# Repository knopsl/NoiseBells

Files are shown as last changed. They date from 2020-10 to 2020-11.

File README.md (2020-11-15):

# Noise Bells synthesizer module

This is a percussion and drone synth module based on ideas presented in the 2015 Hackaday article "[Logic noise: More CMOS cowbell!](https://hackaday.com/2015/04/10/logic-noise-more-cmos-cowbell/)" by Elliot Williams. The PCB and front panel are Kosmo format but the same circuit could be implemented in Eurorack format, or other ±12V formats, with no changes other than PCB, panel, and jack dimensions.

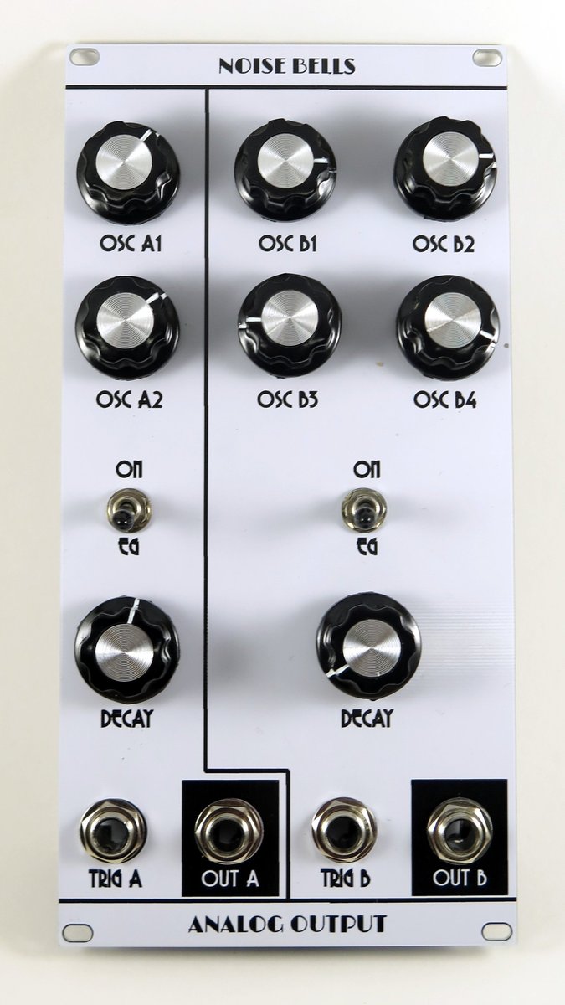
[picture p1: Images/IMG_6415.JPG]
Noise Bells module


The module consists of two separate sections. One is a 2-oscillator circuit based on the "cowbell" section of the Hackaday article. The other is a 4-oscillator circuit, lying sort of halfway between the "cowbell" and "hi hat" designs and designed to use most of the IC functionality left over from the "cowbell" side. Whether it leans more toward bell or cymbal sounds I leave for you to decide. The two sections differ only in the number of oscillators and XORs used.

Aside from a few component value changes, notably a larger capacitor allowing longer decay times, there are a couple of significant modifications to Williams's design:

* The 2-diode "VCA" has been replaced by a 4066 analog switch "VCA" as discussed in the article's comments and at [http://files.electro-music.com/forum/viewtopic.php?highlight=diode+vca&t=23960](http://files.electro-music.com/forum/viewtopic.php?highlight=diode+vca&t=23960). 
* A switch has been added to bypass the EG/VCA section, sending the output of the final XOR straight to the output buffer. This allows using the module for noisy drones.

Pots are used for variable oscillator frequencies and amplitude envelope decay rates. Trigger B input is normalled to Trigger A.

For BOM, schematics, and PCB layout see the [Docs](Docs) folder. The build should be entirely straightforward except, on the first run boards, for the issues mentioned below. Presumably any small signal NPN transistor can be substituted for the 2N3904, though I have not tested any others. 

**Note:** On the first run PCBs the delay pots are connected incorrectly. To fix this, bend the middle leg up and solder it to the leg on its right (pin 2 to pin 3):

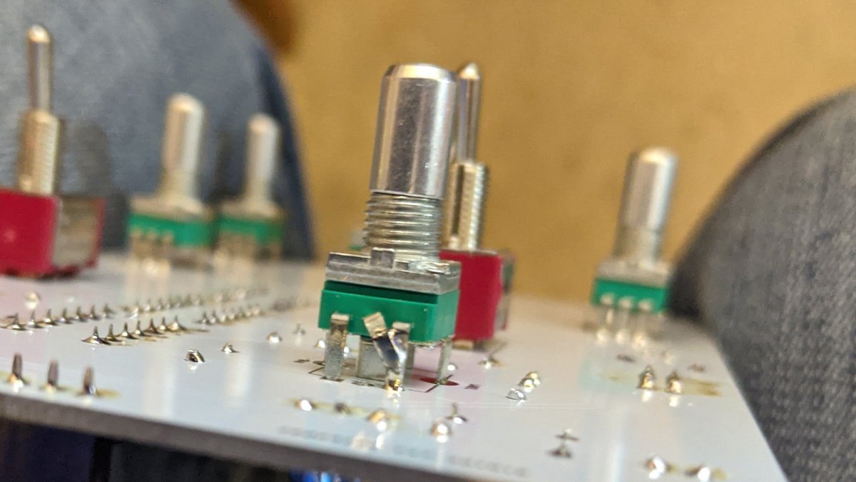
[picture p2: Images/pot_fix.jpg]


This is only for the two delay pots. The six oscillator frequency pots are okay.

Also two capacitors are marked '10uF (47uF?)'. These are 10µF. Unless you like 47µF better of course.

These problems are corrected in the current version.

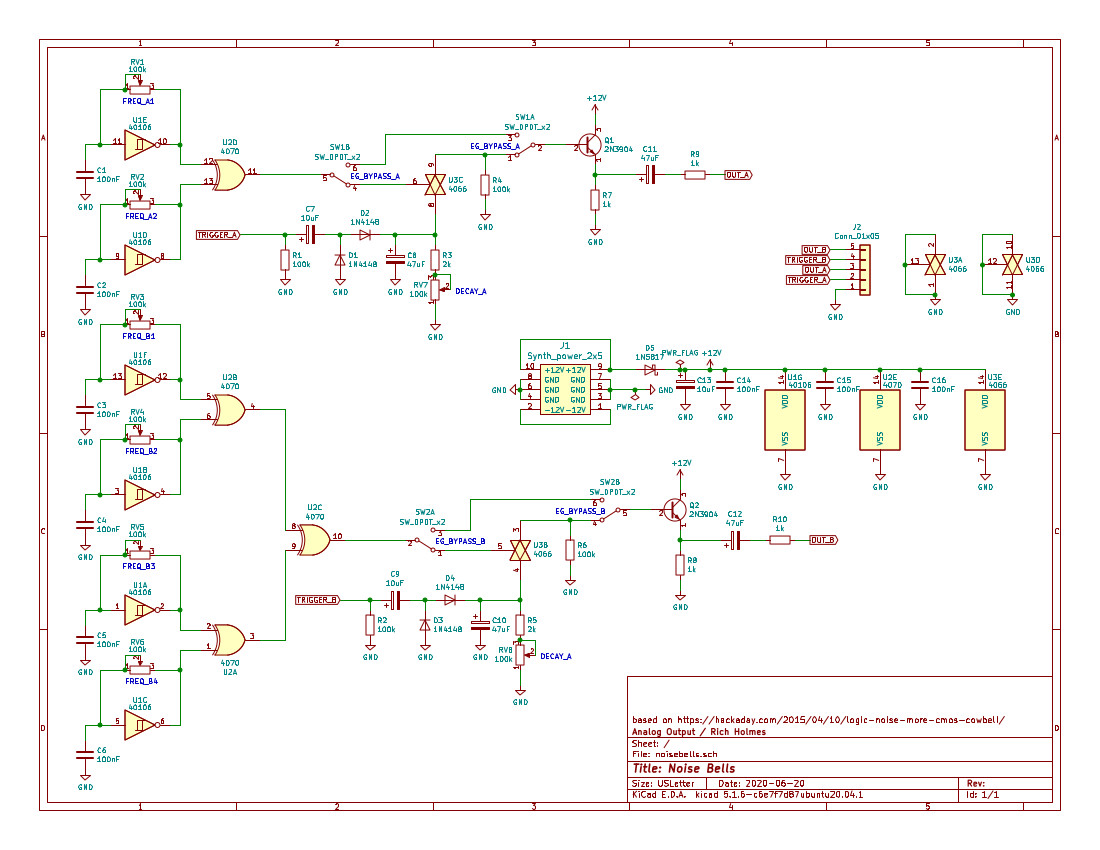
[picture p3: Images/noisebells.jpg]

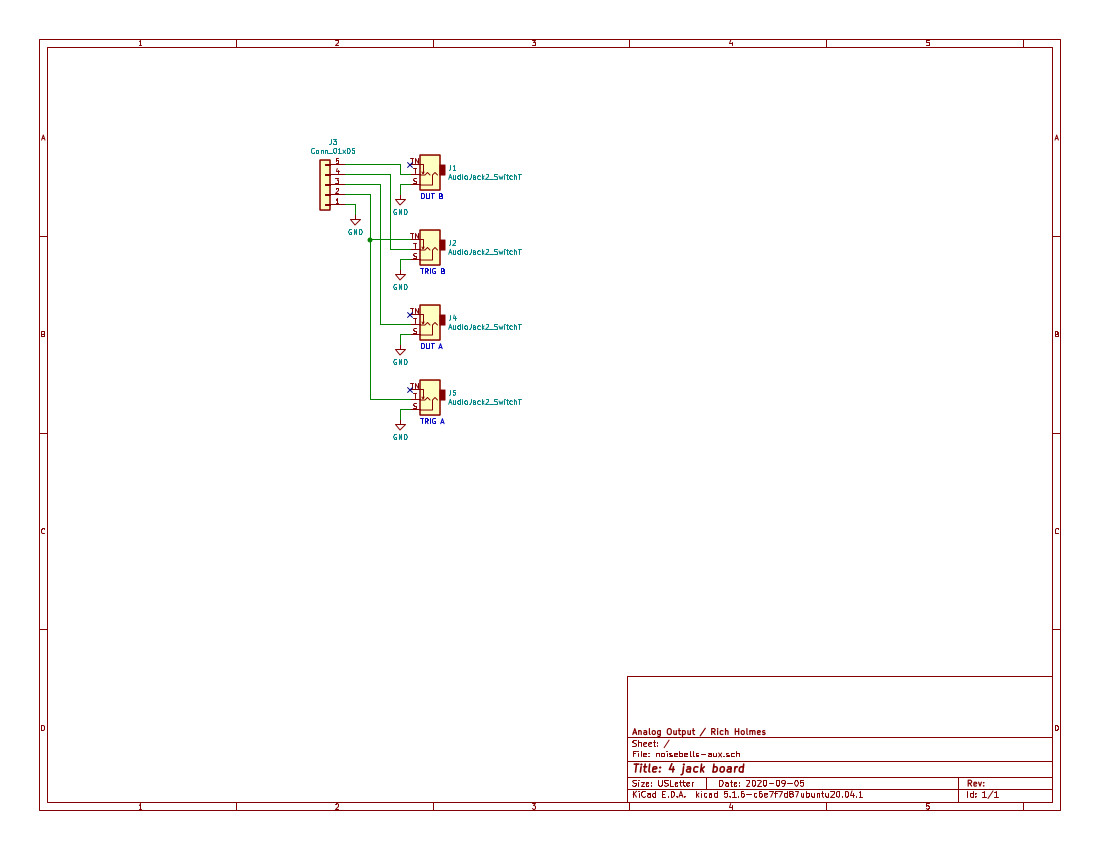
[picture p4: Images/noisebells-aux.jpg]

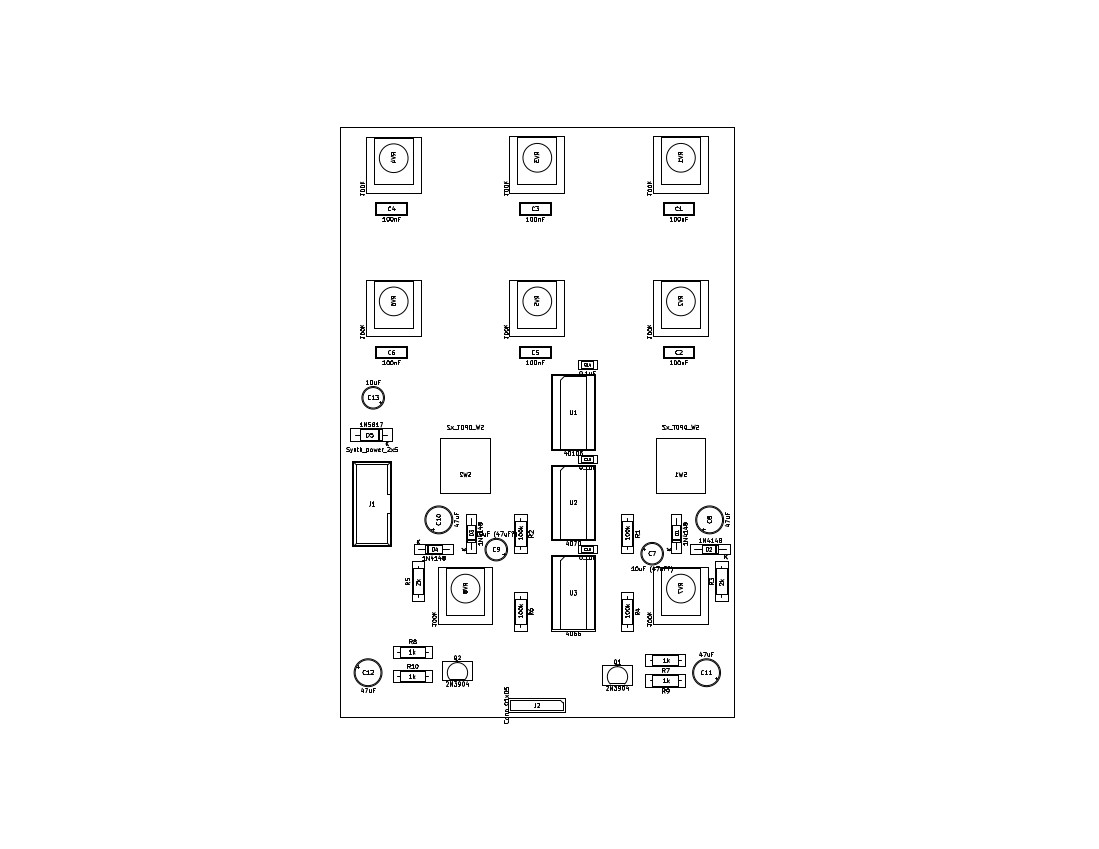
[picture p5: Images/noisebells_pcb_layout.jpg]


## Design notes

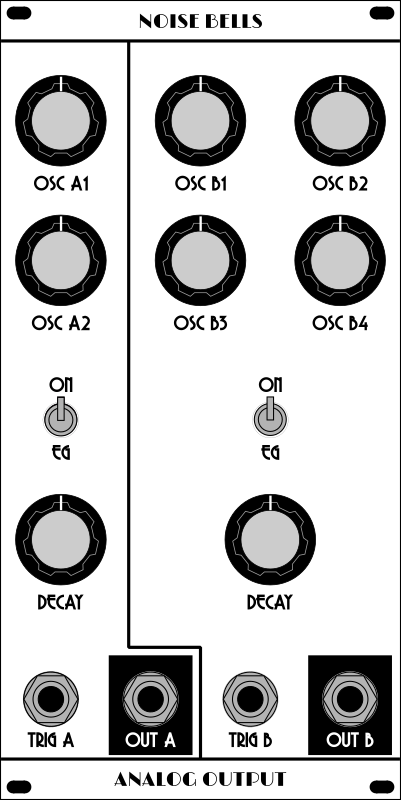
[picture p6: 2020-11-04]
Hardware/Panel/noisebells.png

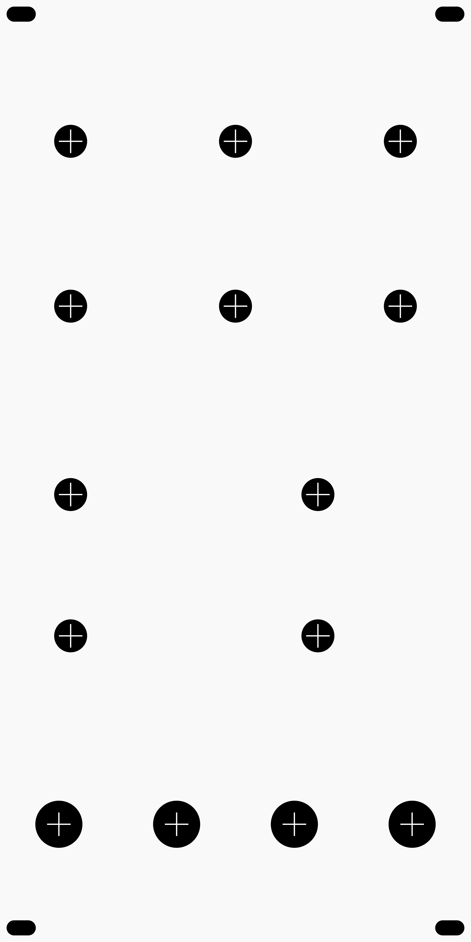
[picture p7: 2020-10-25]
Hardware/Panel/noisebells_holes.png

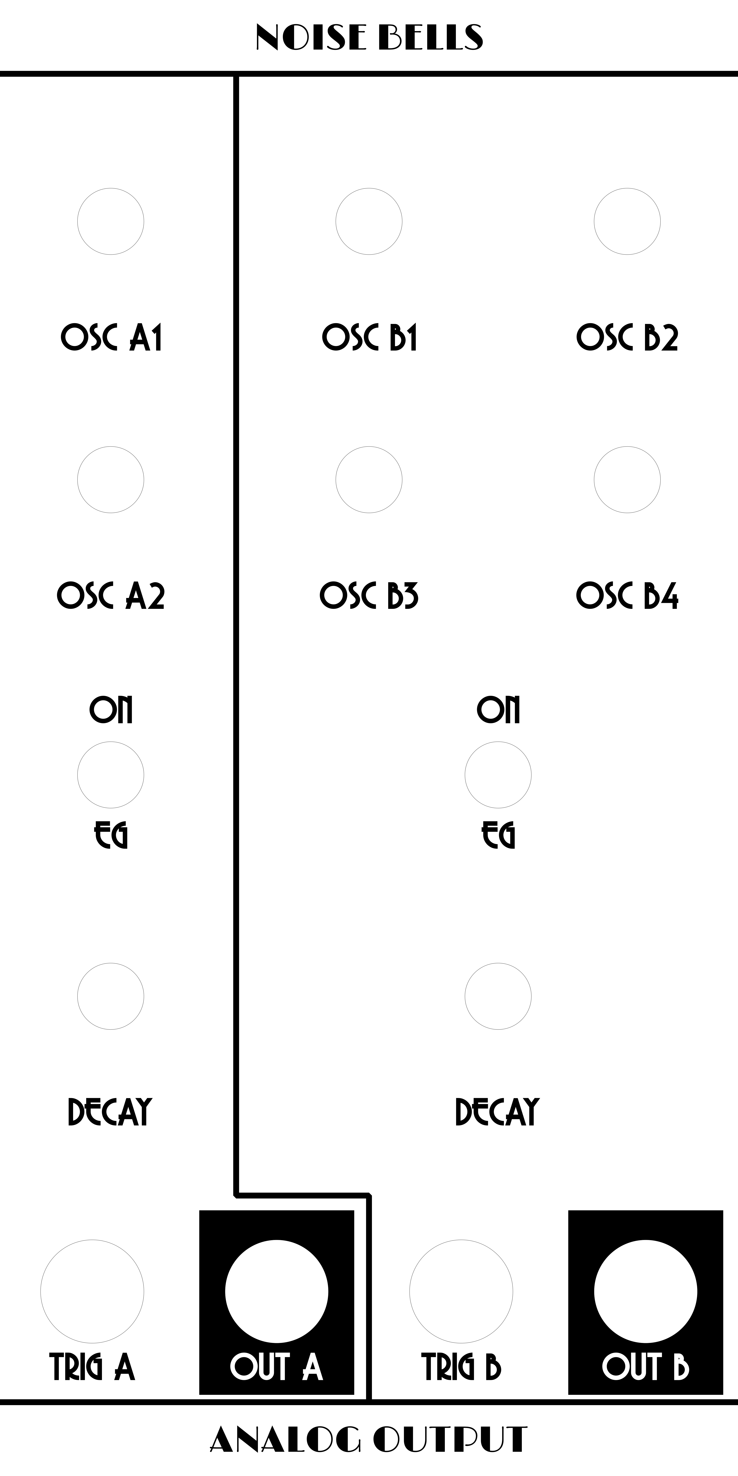
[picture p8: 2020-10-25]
Hardware/Panel/noisebells_art.png

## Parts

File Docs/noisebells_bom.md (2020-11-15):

# Noise Bells BOM

## Main board

| Value | Qty | Part | Description | Vendor |
| ----- | --- | ---- | --- | --- |
| C1, C2, C3, C4, C5, C6 | 6 | 100nF | Polystyrene capacitor | Tayda A-564 |
| C7, C9, C13 | 2 | 10uF | Electrolytic capacitor | Tayda A-4349 |
| C8, C10, C11, C12 | 4 | 47uF | Electrolytic capacitor | Tayda A-4518 |
| C14, C15, C16 | 3 | 0.1uF | Ceramic capacitor | Tayda A-553 |
| D1, D2, D3, D4 | 4 | 1N4148 | 100V 0.15A standard switching diode, DO-35 | Tayda A-157 |
| D5 | 1 | 1N5817 | 20V 1A Schottky Barrier Rectifier Diode, DO-41 | Tayda A-159 |
| J1 | 1 | Synth_power_2x5 | 2x5 pin shrouded header | Tayda A-2939 |
| J2 | 1 | Conn_01x05 | 2.54 mm 5 pin socket | Tayda A-196 (cut to size) |
| Q1, Q2 | 2 | 2N3904 | 0.2A Ic, 40V Vce, Small Signal NPN Transistor, TO-92 | Tayda A-111 |
| R1, R2, R4, R6 | 4 | 100k | Resistor | Tayda A-2248 |
| R3, R5 | 2 | 2k | Resistor | Tayda A-2307 |
| R7, R8, R9, R10 | 4 | 1k | Resistor | Tayda A-2200 |
| RV1, RV2, RV3, RV4, RV5, RV6, RV7, RV8 | 8 | B100k | 9mm vertical board mount potentiometer | Tayda A-1848 |
| SW1, SW2 | 2 | SW_DPDT_x2 | DPDT switch, on-on | Tayda A-3188 |
| U1 | 1 | 40106 | Hex Schmitt trigger inverter | Tayda A-015 |
| U2 | 1 | 4070 | Quad Xor 2 inputs | Tayda A-892 |
| U3 | 1 | 4066 | Quad Analog Switches | Tayda A-555 |
| | 3 | | 14 pin DIP sockets | Tayda A-004 |
| | 8 | | Knobs | |
    
## Jacks board

| Value | Qty | Part | Description | Vendor |
| ----- | --- | ---- | --- | --- |
| J1, J2, J4, J5 | 4 | AudioJack2_SwitchT | Audio Jack, 2 Poles (Mono / TS), Switched T Pole (Normalling) | Tayda A-1121 |
| J3 | 1 | Conn_01x05 | 2.54 mm 5 pin header | Tayda A-197 (cut to size) |

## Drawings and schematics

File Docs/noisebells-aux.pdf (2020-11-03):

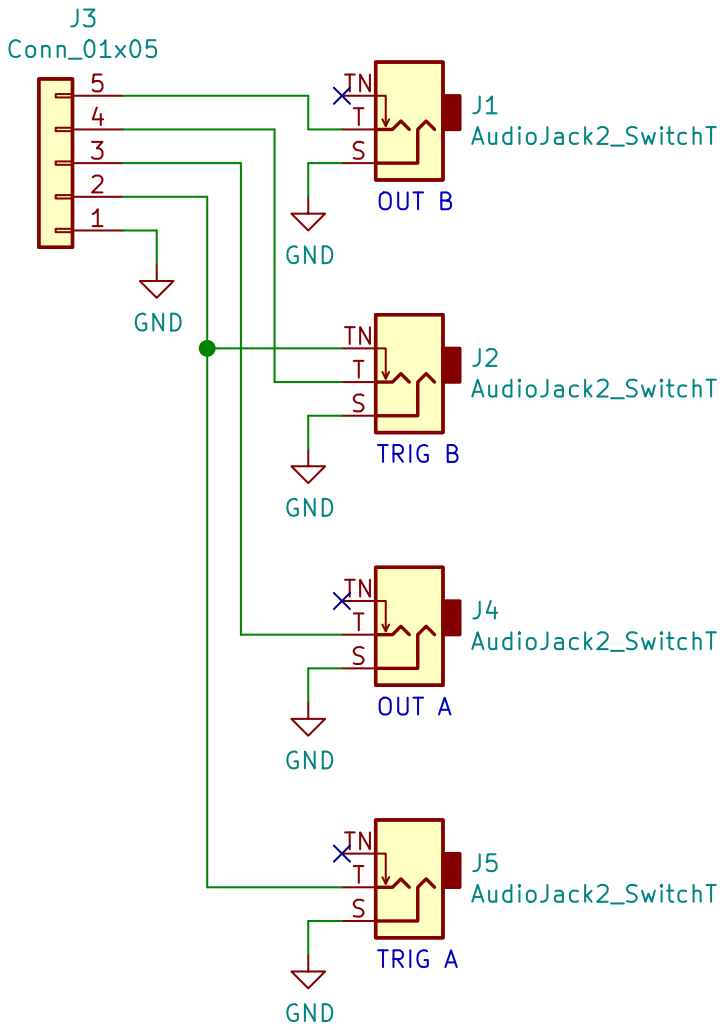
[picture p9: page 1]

TRIG A
File: noisebells-aux.sch Sheet: / Analog Output / Rich Holmes GND

Id: 1/1 Title: 4 jack board

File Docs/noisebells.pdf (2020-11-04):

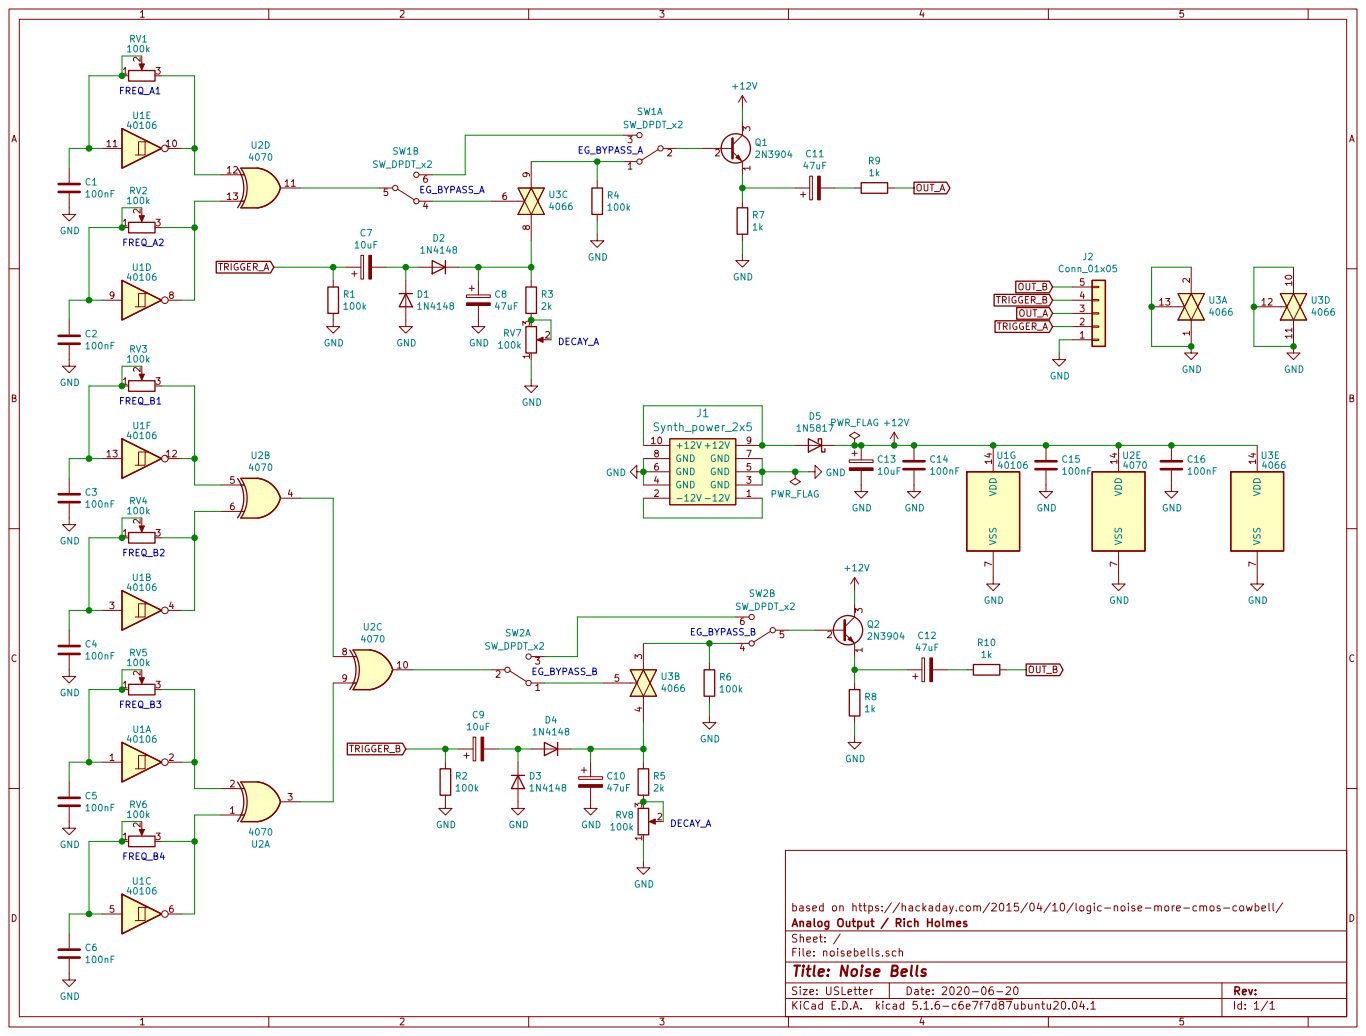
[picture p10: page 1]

based on https://hackaday.com/2015/04/10/logic-noise-more-cmos-cowbell/
File: noisebells.sch Sheet: / Analog Output / Rich Holmes

Id: 1/1 Title: Noise Bells

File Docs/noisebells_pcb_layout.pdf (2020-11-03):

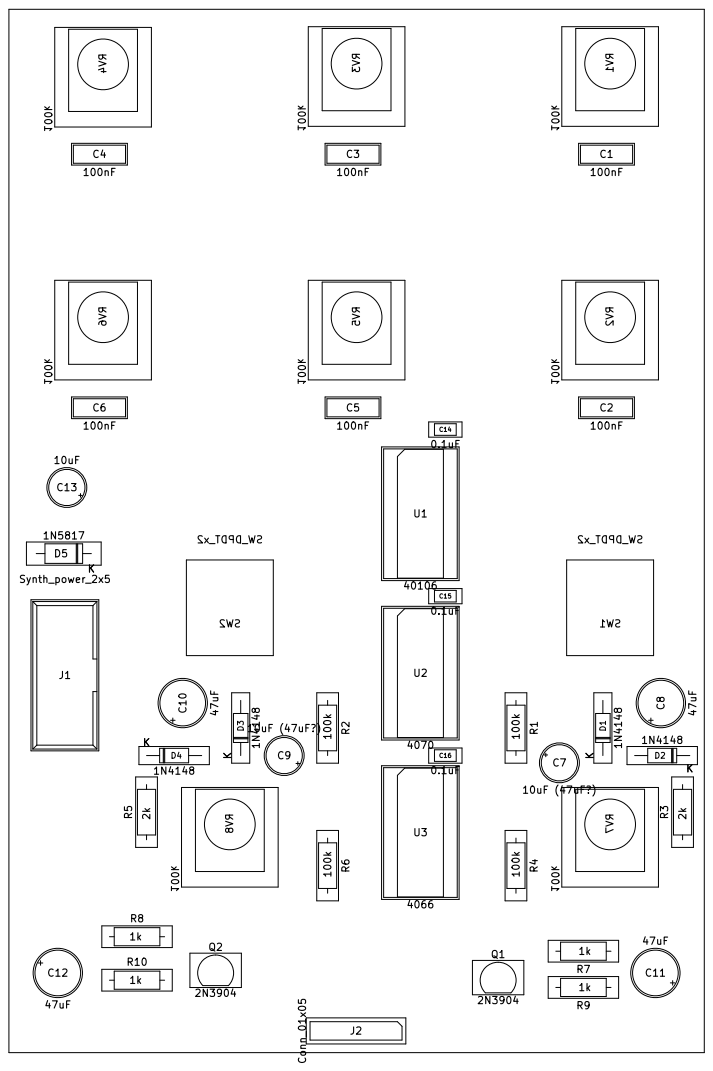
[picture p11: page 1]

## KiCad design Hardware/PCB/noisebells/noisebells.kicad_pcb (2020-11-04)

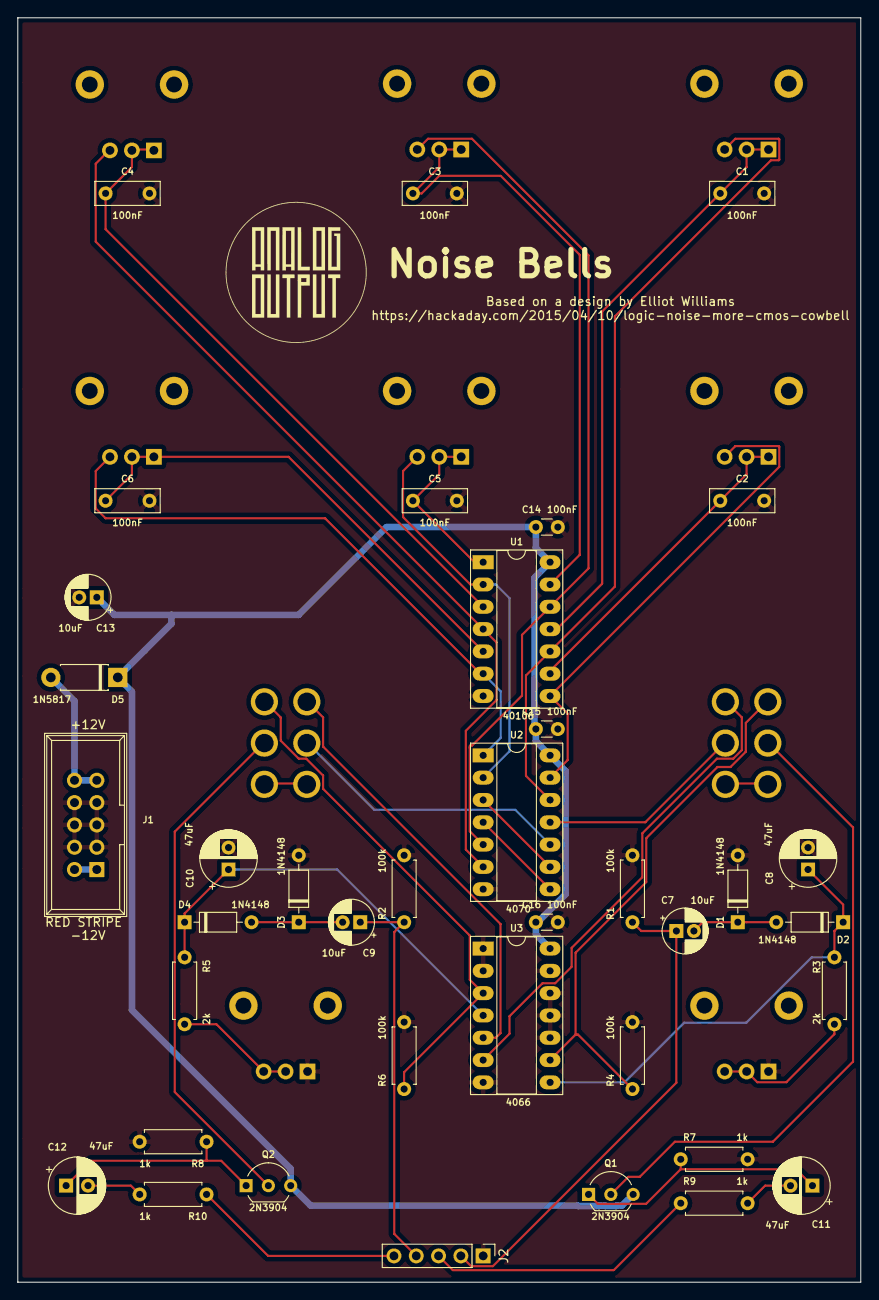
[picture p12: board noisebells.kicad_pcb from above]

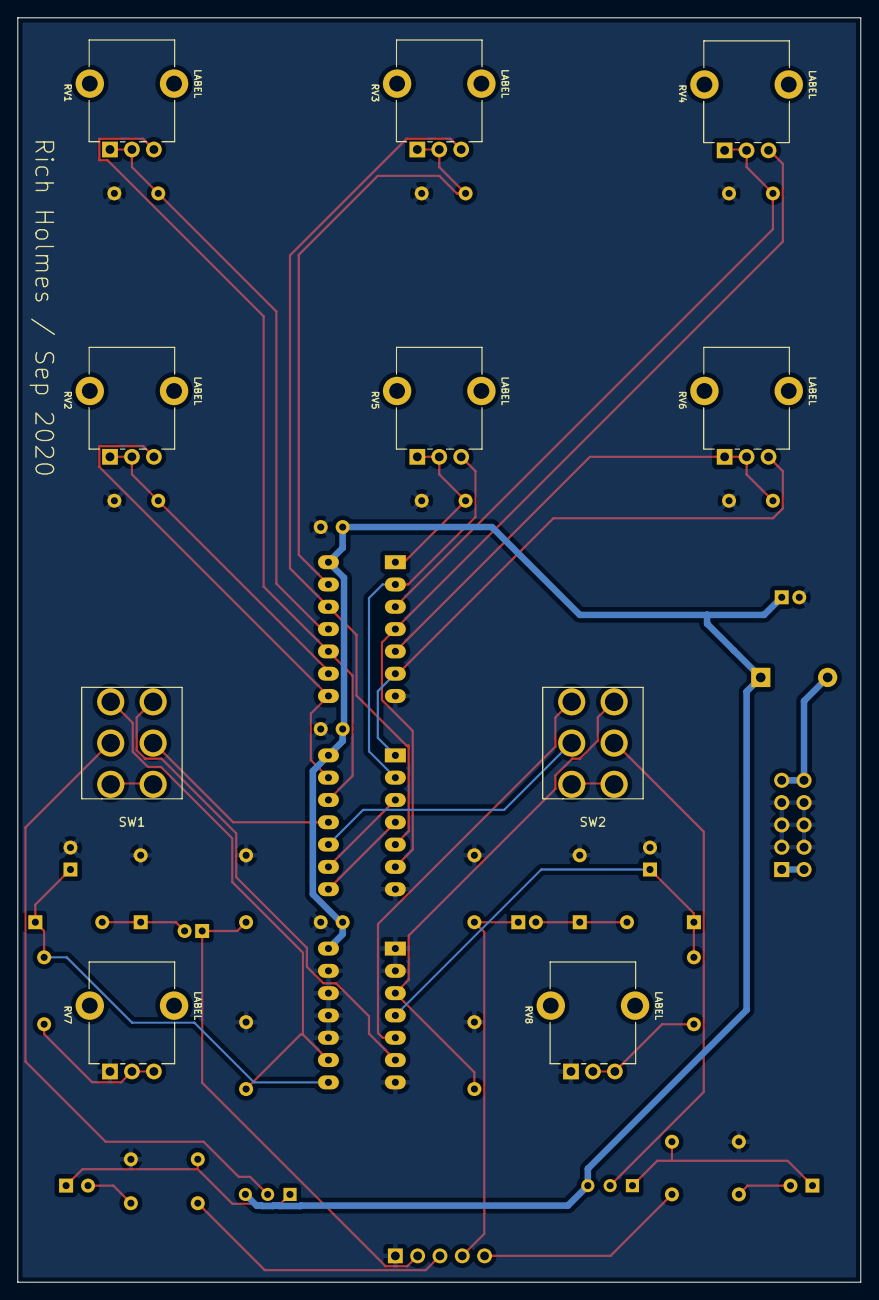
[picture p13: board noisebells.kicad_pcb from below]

Board: 2 copper layers, 96.0 x 144.0 mm, 48 parts (10 on the bottom side), 42 nets.

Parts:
C1, C2, C3, C4, C5, C6: 100nF; C_Rect_L7.2mm_W2.5mm_P5.00mm_FKS2_FKP2_MKS2_MKP2
C7, C9, C13: 10uF; CP_Radial_D5.0mm_P2.00mm
C8, C10, C11, C12: 47uF; CP_Radial_D6.3mm_P2.50mm
C14, C15, C16: 100nF; C_Disc_D3.0mm_W1.6mm_P2.50mm
D1, D2, D3, D4: 1N4148; D_DO-35_SOD27_P7.62mm_Horizontal
D5: 1N5817; D_DO-41_SOD81_P7.62mm_Horizontal
J1: Synth_power_2x5; Power_Header
J2: Conn_01x05; PinHeader_1x05_P2.54mm_Vertical
Q1, Q2: 2N3904; TO-92_Inline_Wide
R1, R2, R4, R6: 100k; R_Axial_DIN0207_L6.3mm_D2.5mm_P7.62mm_Horizontal
R3, R5: 2k; R_Axial_DIN0207_L6.3mm_D2.5mm_P7.62mm_Horizontal
R7, R8, R9, R10: 1k; R_Axial_DIN0207_L6.3mm_D2.5mm_P7.62mm_Horizontal
RV1, RV2, RV3, RV4, RV5, RV6, RV7, RV8: 100k; Potentiometer_Alpha_RD901F-40-00D_Single_Vertical_CircularH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
SW1, SW2: SW_DPDT_x2; DPDT-toggle-switch-1M-seriesx
U1: 40106; DIP-14_W7.62mm_Socket_LongPads
U2: 4070; DIP-14_W7.62mm_Socket_LongPads
U3: 4066; DIP-14_W7.62mm_Socket_LongPads

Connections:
+12V: C13.1, C14.1, C15.1, C16.1, D5.1, Q1.3, Q2.3, U1.14, U2.14, U3.14
GND: C1.2, C2.2, C3.2, C4.2, C5.2, C6.2, C8.2, C10.2, C13.2, C14.2, C15.2, C16.2, D1.2, D3.2, J1.3, J1.4, J1.5, J1.6, J1.7, J1.8, J2.1, R1.2, R2.2, R4.2, R6.2, R7.2, R8.2, RV7.1, RV8.1, U1.7, U2.7, U3.1, U3.2, U3.7, U3.10, U3.11, U3.12, U3.13
unnamed: C1.1, RV1.1, RV1.2, U1.11
unnamed: C2.1, RV2.1, RV2.2, U1.9
unnamed: C3.1, RV3.1, RV3.2, U1.13
unnamed: C4.1, RV4.1, RV4.2, U1.3
unnamed: C5.1, RV5.1, RV5.2, U1.1
unnamed: C6.1, RV6.1, RV6.2, U1.5
unnamed: C7.2, D1.1, D2.2
unnamed: C8.1, D2.1, R3.1, U3.8
unnamed: C9.2, D3.1, D4.2
unnamed: C10.1, D4.1, R5.1, U3.4
unnamed: C11.1, Q1.1, R7.1
unnamed: C11.2, R9.2
unnamed: C12.1, Q2.1, R8.1
unnamed: C12.2, R10.2
unnamed: D5.2, J1.9, J1.10
unnamed: J1.1, J1.2
unnamed: Q1.2, SW1.2
unnamed: Q2.2, SW2.5
unnamed: R3.2, RV7.2, RV7.3
unnamed: R4.1, SW1.1, U3.9
unnamed: R5.2, RV8.2, RV8.3
unnamed: R6.1, SW2.4, U3.3
unnamed: RV1.3, U1.10, U2.12
unnamed: RV2.3, U1.8, U2.13
unnamed: RV3.3, U1.12, U2.5
unnamed: RV4.3, U1.4, U2.6
unnamed: RV5.3, U1.2, U2.2
unnamed: RV6.3, U1.6, U2.1
unnamed: SW1.3, SW1.6
unnamed: SW1.4, U3.6
unnamed: SW1.5, U2.11
unnamed: SW2.1, U3.5
unnamed: SW2.2, U2.10
unnamed: SW2.3, SW2.6
unnamed: U2.3, U2.9
unnamed: U2.4, U2.8
OUT_A: J2.3, R9.1
OUT_B: J2.5, R10.1
TRIGGER_A: C7.1, J2.2, R1.1
TRIGGER_B: C9.1, J2.4, R2.1

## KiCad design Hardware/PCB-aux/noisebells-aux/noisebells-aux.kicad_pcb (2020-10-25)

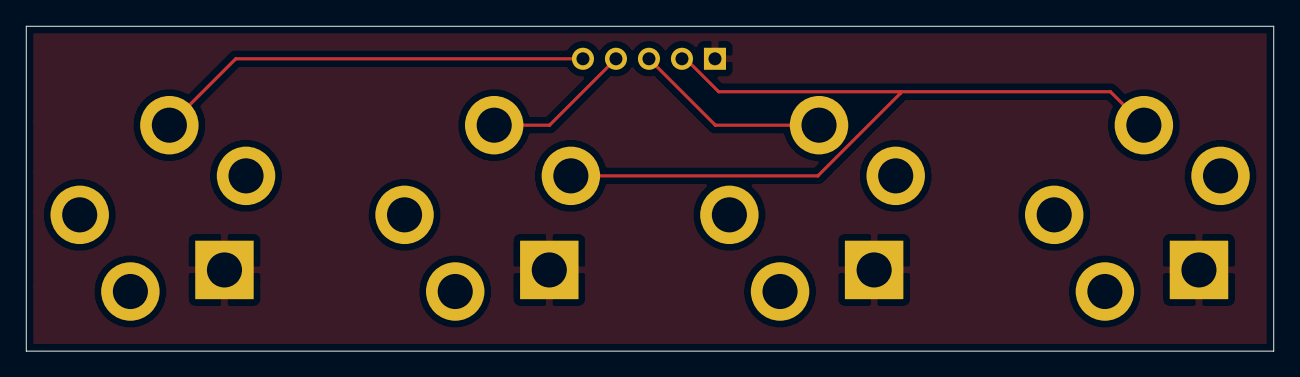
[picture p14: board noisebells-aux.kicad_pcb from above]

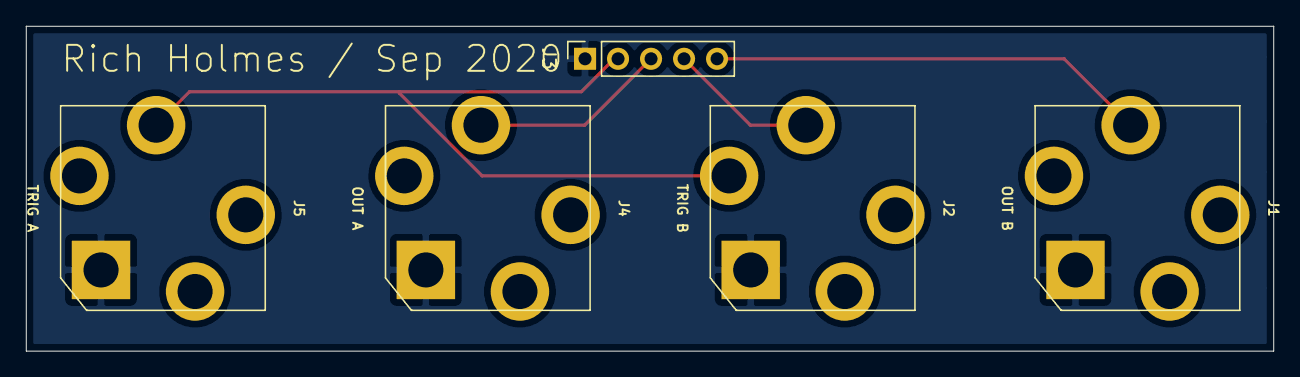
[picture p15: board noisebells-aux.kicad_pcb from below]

Board: 2 copper layers, 96.0 x 25.0 mm, 5 parts (5 on the bottom side), 5 nets.

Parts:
J1, J2, J4, J5: AudioJack2_SwitchT; Jack_6.35mm_PJ_629HAN
J3: Conn_01x05; PinSocket_1x05_P2.54mm_Vertical

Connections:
GND: J1.S, J2.S, J3.1, J4.S, J5.S
unnamed: J1.T, J3.5
unnamed: J2.T, J3.4
unnamed: J2.TN, J3.2, J5.T
unnamed: J3.3, J4.T

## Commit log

2020-10-25 Final design for first run
    [jackboard4-B_Cu.gbr, jackboard4-B_Mask.gbr, jackboard4-B_Paste.gbr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]
2020-11-03 BOM, schematics, and layout
2020-11-04 BOM updates, README
    [noisebells.sch]
2020-11-04 Correct caps value; fix wrong pot direction; move resistor label
    [noisebells-B_Cu.gbr, noisebells-B_Mask.gbr, noisebells-B_Paste.gbr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]
2020-11-04 Add credit to Williams
    [noisebells.kicad_pcb]
2020-11-15 Correction on BOM
2021-01-02 Footprints updated
2021-02-19 Footprint update
